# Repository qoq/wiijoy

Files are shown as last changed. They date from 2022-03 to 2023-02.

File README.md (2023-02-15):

# wiijoy
Adapter for connecting Wii Nunchuck or Wii Classic controller to Commodore, Atari, ZX Spectrum (Kempston) joystick port

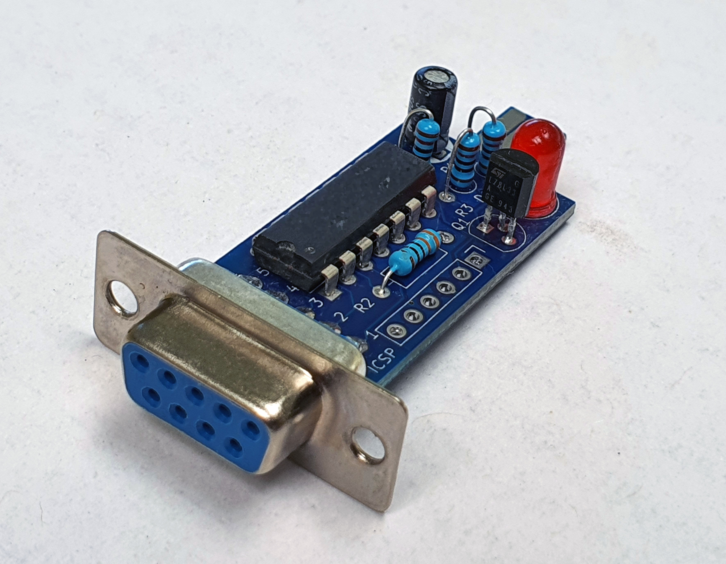
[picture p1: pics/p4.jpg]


The WiiJoy adapter supports both genuine and aftermarket Wii Nunchuck or Classic controllers.
WiiJoy adapter also supports "auto-fire" function (button C on Wii Nunchuck or B,Y,ZL,ZR on Wii Classic controller).

Beginning with version 1.0.6 (released Feb 05, 2023), the following features are supported:
- Accelerometer support for Nunchuck
- Up/Down direction swap
- Atari 2600 paddle-controller support 
- 2-button fire mode for Atari 7800 (BETA, not tested)

Nunchuck configuration:
- Holding Z while powering on enables 2-button fire mode
- Holding C while powering on enables accelerometer mode
- Holding DOWN while powering on swaps up and down direction
- Holding UP while powering on enables Atari 2600 paddle controller mode. In this mode, holding DOWN swaps L/R paddles

Wii Classic controller configuration:
- Select(-) button turns on 2-button fire mode
- Start(+)  button turns on up/down direction swap
- Home button resets all settings and restarts WiiJoy
- Holding UP on either stick while powering on (or while pressing Home) enables Atari 2600 paddle controller mode.

For Atari 7800 2-button mode:
Current PCB layout does not have traces connecting DB9 pins 5 and 9 to the MCU -- you must add two jumper wires (see schematic)
Turning 2-button support on is disables the auto-fire function

For Atari 2600 paddle controller mode:
Current PCB layout does not have circutry for this mode. You must add 4 resistors and 2 capacitors (see https://github.com/qoq/wiijoy/blob/main/pics/schematic_v2.png)

### Connecting Wii Nunchuck:
The Nunchuck's connector has three pins on one side and two pins on the other. Be sure to match them to 3 and 2-pin pads on WiiJoy PCB.

### Testing

- Plug WiiJoy into a joystick port. The LED should light up.
- Connect Wii Nunchuck/Classic  to the adapter. The LED should turn off (Controller detected). If the LED stays on, check Nunchuck connection.
- Press fire (Z). The LED should light up.
- Press (C) button. The LED should start blinking (this is the auto-fire function of the adapter).

Note that the metal "ears" of the pictured DB9 connector may need to be bent or cut to fit on some Atari machines. You can remove metal casing altogether, 
but you may need to glue two plastic parts of the connector together so they don't fall apart. Alternatively, you can use a different type of DB9 connector.

### Bill of materials

- [1] Resistor 330 Ohm 1/8w
- [3] Resistor 10 kOhm 1/8w
- [1] 5mm LED
- [1] 10 uF x 16v capacitor 
- [1] 3.3v voltage regulator -- STMicro L78L33ACZ or similar, TO92 package
- [1] DB9 female connector
- [1] Programmed PIC16Fxxx Microcontroller and PCB (eBay)

Additional parts required for 2600 paddle controler mode:
- [2] Resistor 330 Ohm 1/8w
- [2] Resistor 56 kOhm  (approximate value -- might neeed adjustments to calibrate/center paddle on screen)
- [2] 10 uF x 16v capacitor 

### The PCB & programmed MCU or complete DYI kit are available for purchasing on eBay

Have fun!

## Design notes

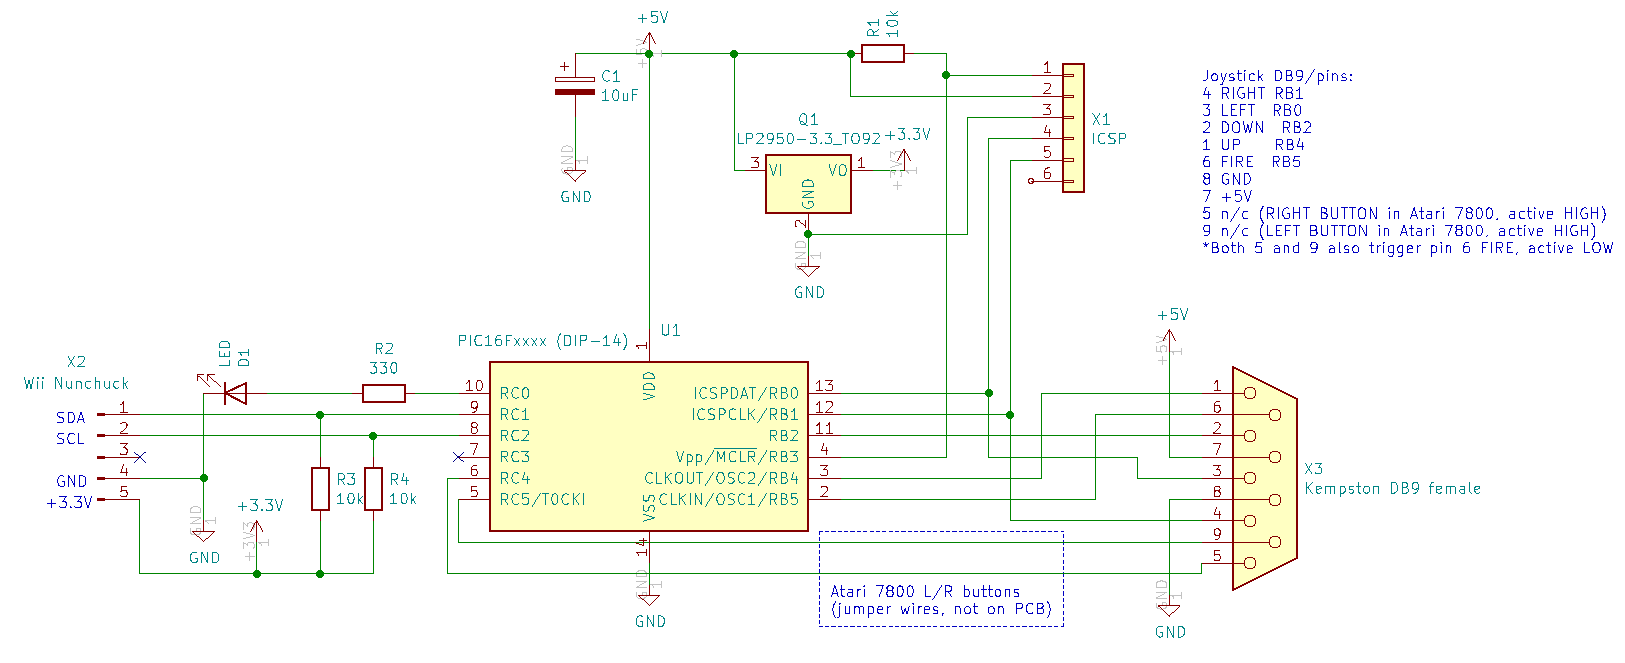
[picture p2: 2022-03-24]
pics/schematic.png

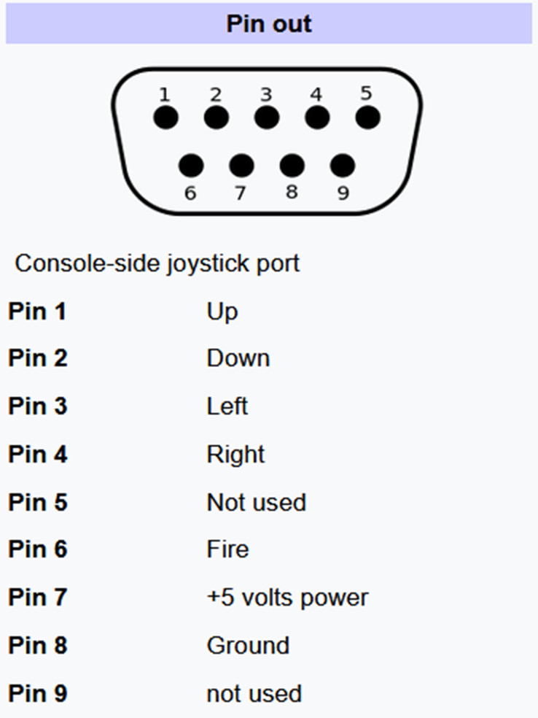
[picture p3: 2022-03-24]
pics/pinout.png

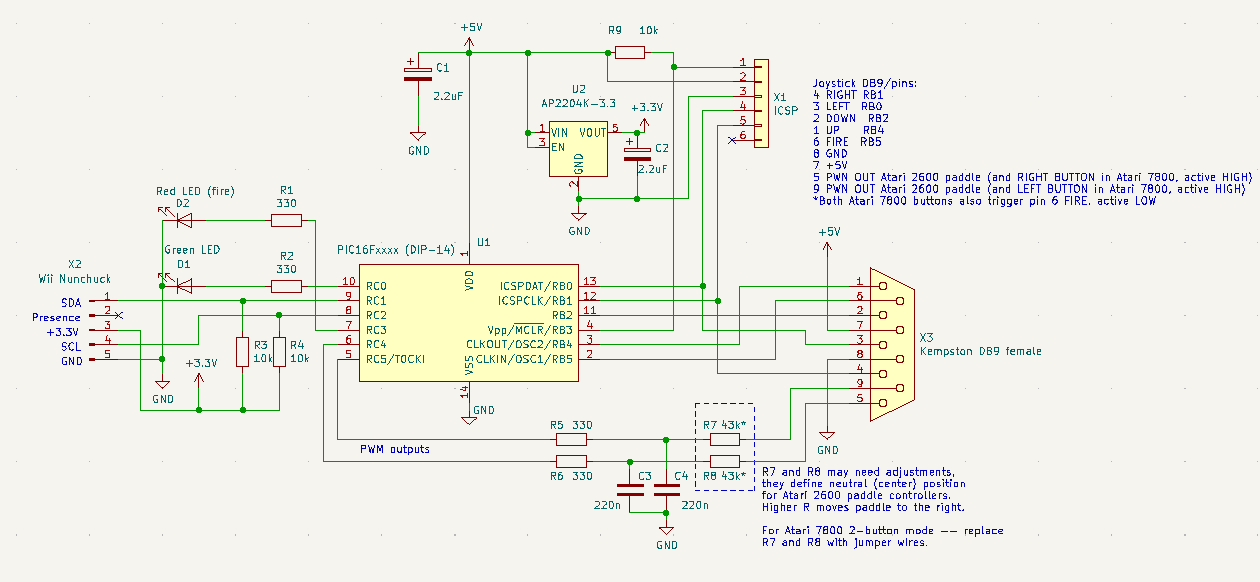
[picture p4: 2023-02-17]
pics/schematic_v2.png

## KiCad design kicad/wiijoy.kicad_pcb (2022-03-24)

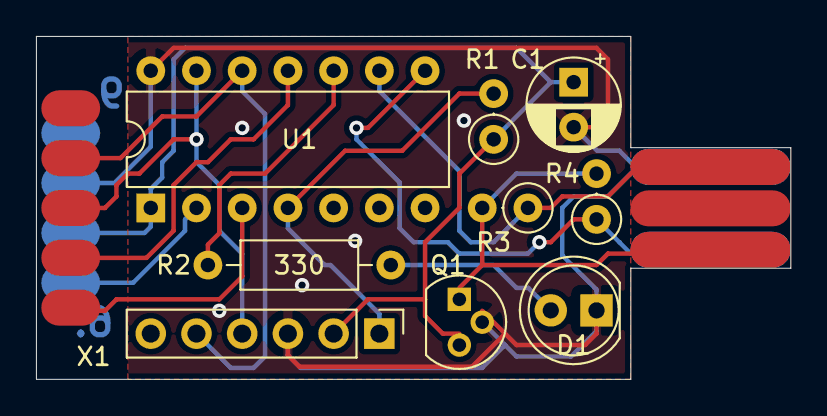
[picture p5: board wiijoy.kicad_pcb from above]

Board: 2 copper layers, 41.9 x 19.1 mm, 9 parts (0 on the bottom side), 10 nets.

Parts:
C1: 10uF; CP_Radial_D5.0mm_P2.50mm
D1: LED; LED_D5.0mm
Q1: LP2950-3.3_TO92; TO-92
R1, R3, R4: 10k; R_Axial_DIN0207_L6.3mm_D2.5mm_P2.54mm_Vertical
R2: 330; R_Axial_DIN0207_L6.3mm_D2.5mm_P10.16mm_Horizontal
U1: PIC16F15223-I/P; DIP-14_W7.62mm
X1: ICSP; PinHeader_1x06_P2.54mm_Vertical

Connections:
+3V3: Q1.1, R3.2, R4.2
+5V: C1.1, Q1.3, R1.1, U1.1, X1.2
GND: C1.2, D1.1, Q1.2, U1.14, X1.3
unnamed: D1.2, R2.1
unnamed: R1.2, U1.4, X1.1
unnamed: R2.2, U1.10
unnamed: R3.1, U1.9
unnamed: R4.1, U1.8
unnamed: U1.12, X1.5
unnamed: U1.13, X1.4

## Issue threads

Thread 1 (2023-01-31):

7800 support - jumpers for pins 5 and 9

RetroInVitro, 2023-01-31:
Do you just mean to have a wire between 5 and 9 somewhere along the way between the DB9 connector and the MCU?

qoq, 2023-02-04:
The board does not have traces from DB9 pins 5 and 9 to the MCU. You need to add them using jumper wires.

RetroInVitro, 2023-02-04:
> The board does not have traces from DB9 pins 5 and 9 to the MCU. You need to add them using jumper wires.

Can you tell if the attached photos for the pins 5 and 9 are connected to the MCU properly?

I don't have an Atari 7800 but I can tell with a Wii Gamepad that pressing Select disables autofire and pressing Start on it enables it.   Is this an indicator that the current beta 7800 mode is working properly?

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

qoq, 2023-02-04:
Jump wires are connected properly. Start  & Select buttons on Classic controller enable/disable two-button 7800 mode. I cannot test it, unfortunately, as I don't have a 7800. Autofire is disabled in the 2-button mode. On nunchuck holding Z while powering up  enables 2-button mode.

RetroInVitro, 2023-02-04:
Thank you for the validation.   If I understood you properly, being able to toggle autofire on or off is a good test that pins 5 and 9 are connected and that the current beta functionality is at least recognizing this new mode?

Closed 2023-02-04.

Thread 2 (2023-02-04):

Compatibility with the ColecoVision in regular 1-button or 7800 mode

RetroInVitro, 2023-02-04:
So the ColecoVision can use single button Atari DB9 controllers stock for single button games.   However, the WiiJoy doesn't seem to like acting as either a regular 1-button 2600 (w/o jumpers) or 2-button 7800 controller on the ColecoVision when a regular 2600 and 7800 controller work respectively.

I recognize there is no stated support for the ColecoVision.   I'm just trying to understand the extent of 2600 and 7800 (beta as of this writing) compatibility with the adapter.   Thank you!

qoq, 2023-02-04:
Don't have ColecoVision. Assuming that the pinout is the same, one possible reason for WiijJoy to not work is that it uses internal weak pull-ups on data lines. They might not be sufficient to drive inputs on ColecoVision. If you can add pull-up resistors between pins 1,2,3,4,6 of the DB9 connector and +5v (pin 7 on DB9), it might help. Resistors between 4.7k and 10k should work.

RetroInVitro, 2023-02-04:
Thank you for the explanation!

qoq, 2023-02-05:
I think the issue is that ColecoVision does not supply power (+5V) on pin7 of the DB9 connector, so WiiJoy cannot function. It works fine with Atari 2600.

Closed 2023-02-05.

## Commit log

2023-02-05 Accelerometer support, up/down swap support
2023-02-15 atari2600 mode added
    [wiijoy2.sch]
